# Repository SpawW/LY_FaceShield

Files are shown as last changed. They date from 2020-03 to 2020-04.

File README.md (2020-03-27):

# LY_FaceShield
Nome do projeto: LY Face Shield (Luiti e Yuri - Face Shield) 

Todos os arquivos deste projeto foram feitos tendo em mente:
1) menor tempo de impressão
2) menor consumo de insumos
3) menor tempo de montagem
4) boa resistencia durante o uso
5) impressão sem "desperdicios" de insumo e por isso devem ser impressos:
5.1) sem utilizar infil algum
5.2) sem utlizar fixação por software (brim ou outros)
5.3) sem utilizar suportes

A Bárbara tostes subiu vários arquivos relacionado a este tipo de máscara: https://www.dropbox.com/sh/dtmmtzgbqdhi0c7/AADPNCneKkb_lSbL7qFN4Hlxa?dl=0

O principal objetivo desta máscara é proteger o usuário contra "espirros" dos pacientes. 

== Arquivos == 
* Face Mask Drake Mix v5_Botton.stl - Parte inferior da máscara / escudo. 
-- O objetivo desta parte é proteção do usuário e do paciente contra movimentos bruscos (como levantar e abaixar).

* Face Mask Drake Mix v5_Upper.stl 
-- O objetivo desta parte é segurar o shield (acetato, pet ou outro plástico transparente) na cabeça do usuário.
-- Ela foi feita de forma minimalista para utilizar a menor quantidade de insumo de impressão (filamento) e o menor tempo, mantendo-se ainda assim flexível e com forma constante.

* Fast Face Mask_Upper_External.stl
-- Mesmo objetivo da parte anterior (Upper) com a diferença de ter pinos laterais de fixação do shield.
-- Mede 15mm de altura

* Adail - Fast Face Mask - TOP com Z em 12mm.stl
-- Idem a anterior mas com 12mm de altura (customização feita pela Bárbara Tostes)

* Fast Face Mask - Upper - com pinos com Z em 10mm.stl
-- Idem a anterior mas com 10mm de altura

* Face Mask Drake Mix v5_Clipe.stl
-- Clipe de conforto trazeiro para juntar as ligas de fixação na cabeça

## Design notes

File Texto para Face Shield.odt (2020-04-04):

HIGIENIZAR E ESTERILIZAR ANTES DE USAR!

LEIA ATENTAMENTE:

Este dispositivo é um protótipo e não possui qualquer tipo de licença ou certificação.

Em especial, por indisponibilidade de matéria prima no mercado local, este dispositivo não está em conformidade com a RESOLUÇÃO - RDC Nº 356, DE 23.03.2020, que preconiza espessura mínima de 0.5mm para o visor frontal, tendo o visor do presente dispositivo espessura de 0.25 mm.

O suporte plástico deste dispositivo foi desenvolvido através de impressão 3D FDM com filamento ABS, o visor frontal foi confeccionado a partir de folhas de acetato, e a tira elástica a partir elástico para aviamentos.

Apesar de terem sido utilizadas boas práticas de higiene, o dispositivo foi montado manualmente em ambiente não estéril e deve ser higienizado e esterilizado com solução apropriada antes e depois da sua utilização, observando-se a adequabilidade do processo de esterilização aos tipos de materiais presentes no dispositivo e à destinação que será dada ao mesmo.

Levando em consideração a pandemia de Covid-19, bem como o estado de emergência decretado pela grande maioria dos governos estaduais, este dispositivo é cedido gratuitamente, como está, sem garantias, e a utilização do mesmo é de responsabilidade do profissional que o manusear.

HIGIENIZAR E ESTERILIZAR ANTES DE USAR!

LEIA ATENTAMENTE:

Este dispositivo é um protótipo e não possui qualquer tipo de licença ou certificação.

Em especial, por indisponibilidade de matéria prima no mercado local, este dispositivo não está em conformidade com a RESOLUÇÃO - RDC Nº 356, DE 23.03.2020, que preconiza espessura mínima de 0.5mm para o visor frontal, tendo o visor do presente dispositivo espessura de 0.25 mm.

O suporte plástico deste dispositivo foi desenvolvido através de impressão 3D FDM com filamento ABS, o visor frontal foi confeccionado a partir de folhas de acetato, e a tira elástica a partir elástico para aviamentos.

Apesar de terem sido utilizadas boas práticas de higiene, o dispositivo foi montado manualmente em ambiente não estéril e deve ser higienizado e esterilizado com solução apropriada antes e depois da sua utilização, observando-se a adequabilidade do processo de esterilização aos tipos de materiais presentes no dispositivo e à destinação que será dada ao mesmo.

Levando em consideração a pandemia de Covid-19, bem como o estado de emergência decretado pela grande maioria dos governos estaduais, este dispositivo é cedido gratuitamente, como está, sem garantias, e a utilização do mesmo é de responsabilidade do profissional que o manusear.

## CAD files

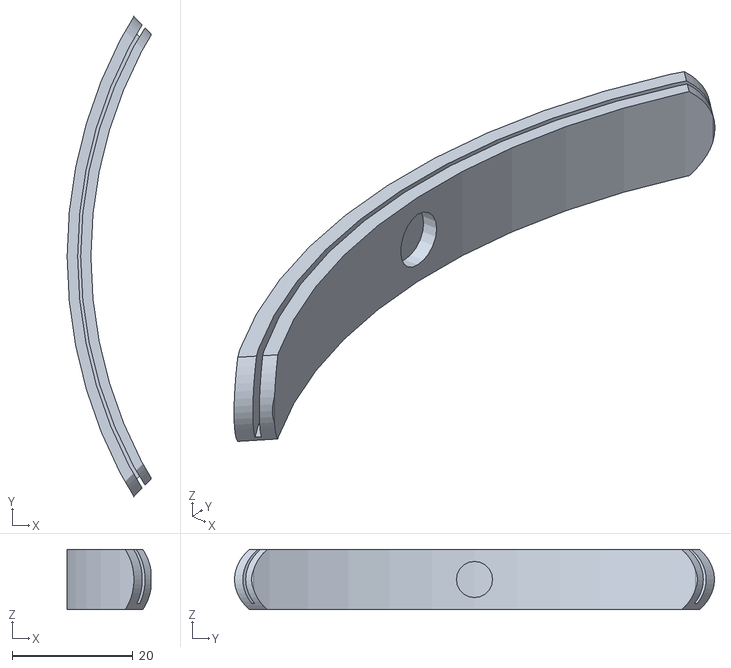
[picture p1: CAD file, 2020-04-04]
Fast Mask v9 - Mr.Spock 10mm Encaixe - Botton.stl
13.9 x 79.6 x 10.0

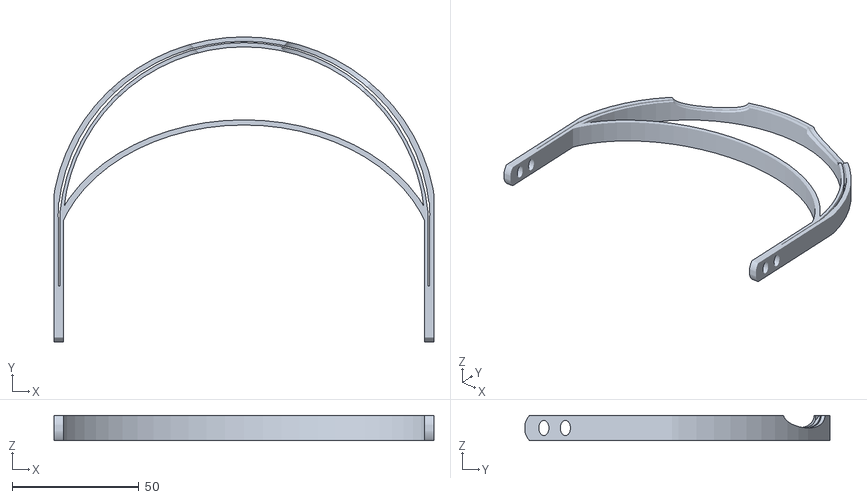
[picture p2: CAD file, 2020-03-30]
Fast Mask v8 - Mr.Spock 10mm Encaixe - Upper.stl
150.0 x 120.5 x 10.0

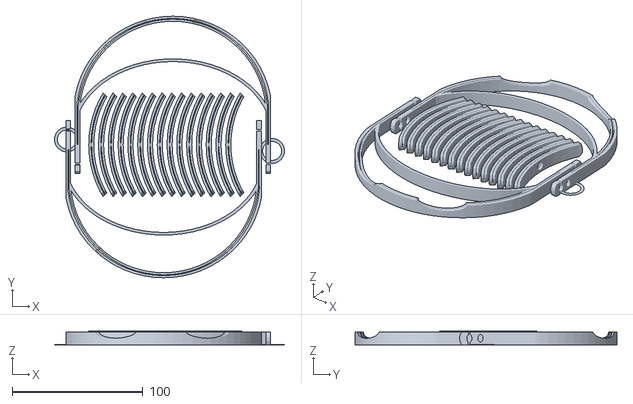
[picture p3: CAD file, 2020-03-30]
Fast Mask v8 - Mr.Spock 10mm Encaixe - 2xUpper - 15xBotton.stl
176.2 x 200.5 x 10.5

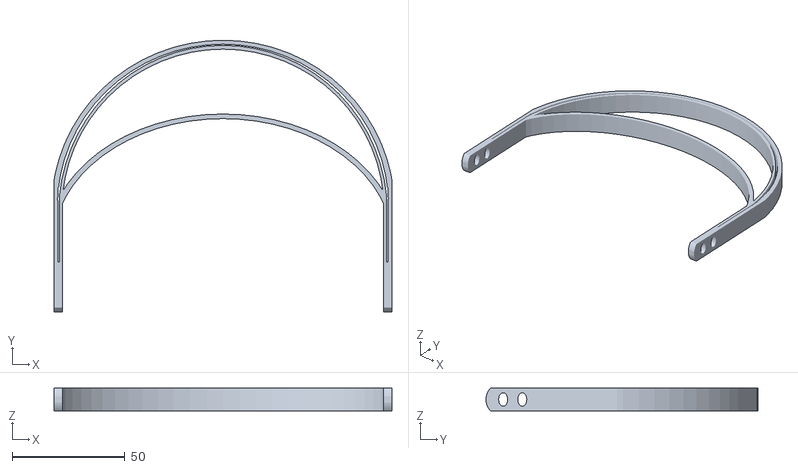
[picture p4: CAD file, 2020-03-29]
Fast Mask v7 - Mr.Spock 10mm Encaixe.stl
150.0 x 120.5 x 10.0

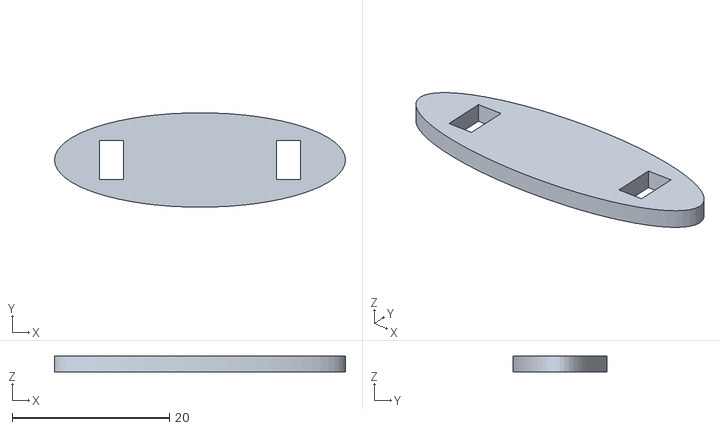
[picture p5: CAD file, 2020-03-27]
Face Mask Drake Mix v5_Clipe.stl
37.0 x 12.0 x 2.00

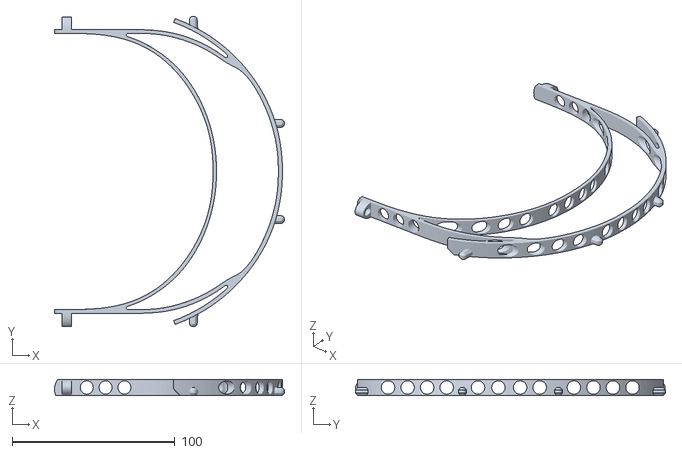
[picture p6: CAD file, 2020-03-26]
Fast Face Mask - Upper - com pinos com Z em 10mm.stl
141.5 x 191.0 x 10.0

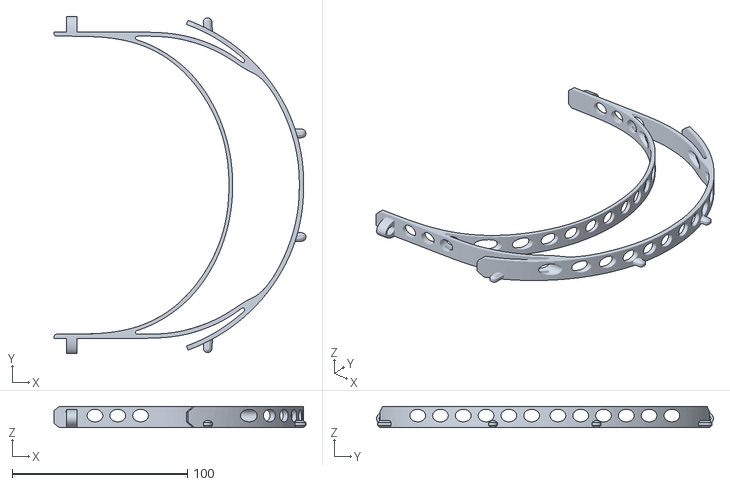
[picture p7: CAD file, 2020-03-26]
Adail - Fast Face Mask - TOP com Z em 12mm.stl
143.7 x 192.2 x 12.0

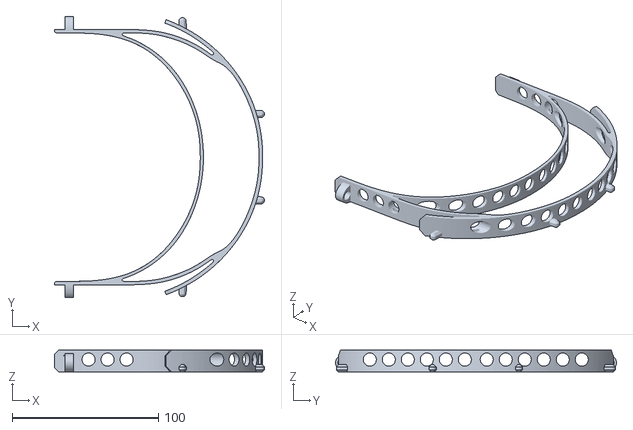
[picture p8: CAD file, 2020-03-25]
Fast Face Mask_Upper_External.stl
143.7 x 192.3 x 15.0

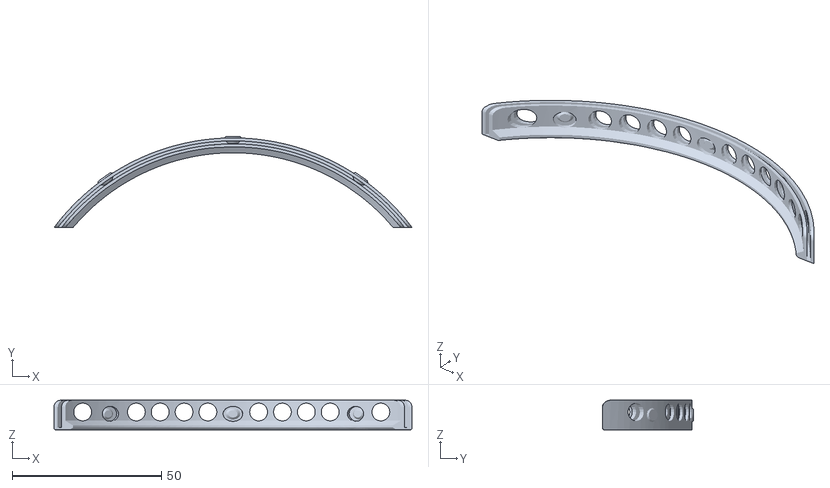
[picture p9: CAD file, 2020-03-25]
Face Mask Drake Mix v5_Botton.stl
120.1 x 30.6 x 10.0

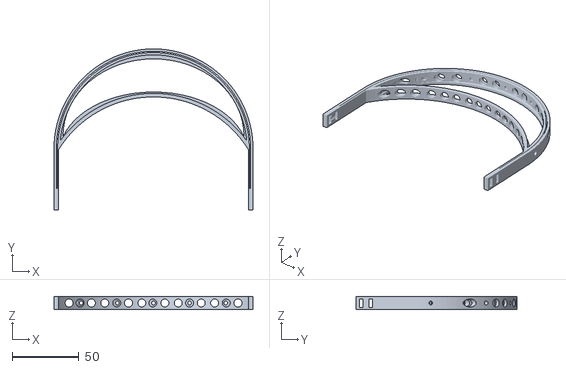
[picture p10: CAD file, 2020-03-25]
Face Mask Drake Mix v5_Upper.stl
149.0 x 120.8 x 10.0

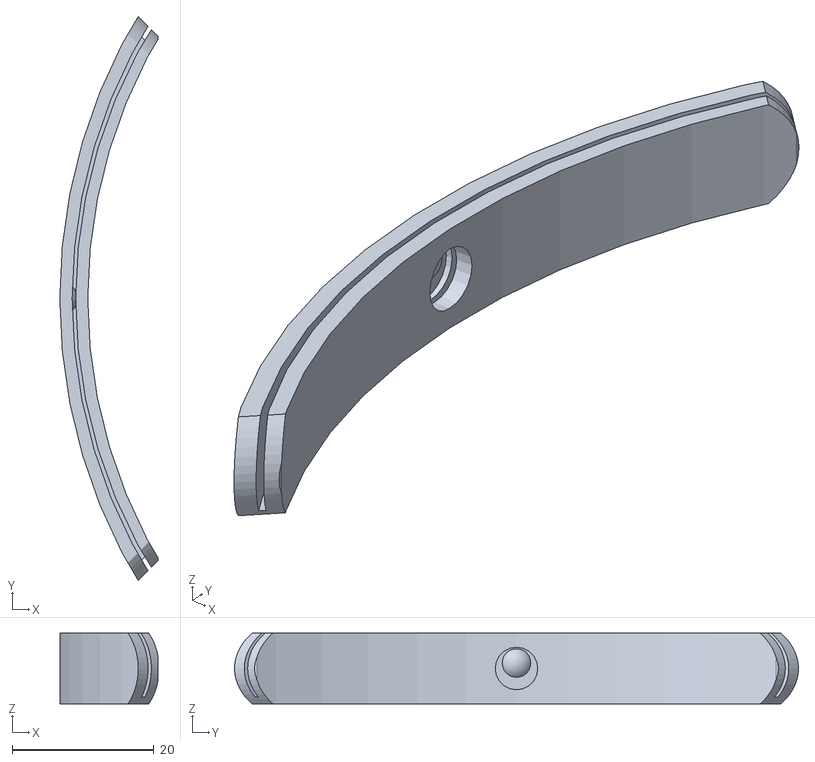
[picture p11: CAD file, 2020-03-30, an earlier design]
old/Fast Mask v8 - Mr.Spock 10mm Encaixe - Botton.stl
13.9 x 79.6 x 10.0

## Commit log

2020-03-25 Add external upper mask
    [Fast Face Mask_Upper_External.stl]
2020-03-26 Colaboração da Bárbara Tostes
    [Adail - Fast Face Mask - TOP com Z em 12mm.stl]
2020-03-29 Refactoring - Spock
    [Fast Mask v7 - Mr.Spock 10mm Encaixe.stl]
2020-03-30 Add version 8 of Fast Mask
    [Fast Mask v8 - Mr.Spock 10mm Encaixe - 2xUpper - 15xBotton.stl, Fast Mask v8 - Mr.Spock 10mm Encaixe - Upper.stl]
2020-03-30 Create folder for old versions
    [Fast Mask v7 - Mr.Spock 10mm Encaixe.stl]
2020-03-31 Corrigindo nome do arquivo
    [Fast Mask v8 - Mr.Spock 10mm Encaixe - Botton.stl]
2020-04-04 Update botton model
    [Fast Mask v8 - Mr.Spock 10mm Encaixe - Botton.stl, Fast Mask v9 - Mr.Spock 10mm Encaixe - Botton.stl]
